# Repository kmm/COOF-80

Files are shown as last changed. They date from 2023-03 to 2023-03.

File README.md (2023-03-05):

# C00F-80

---
> A Lockdown-inspired Junkbox Z80 System

## Overview
Designed and built from on-hand parts in early 2020, COOF-80 (stylized in hexadecimal compatible as C00F-80) is Z80 system implementation that would be relatively sophisticated if it was 1980. Unfortunately it is not 1980, so it's more of an example of the most basic level of computing and a fun toy model computer to play with. Includes a simple and probably buggy interactive ROM monitor.

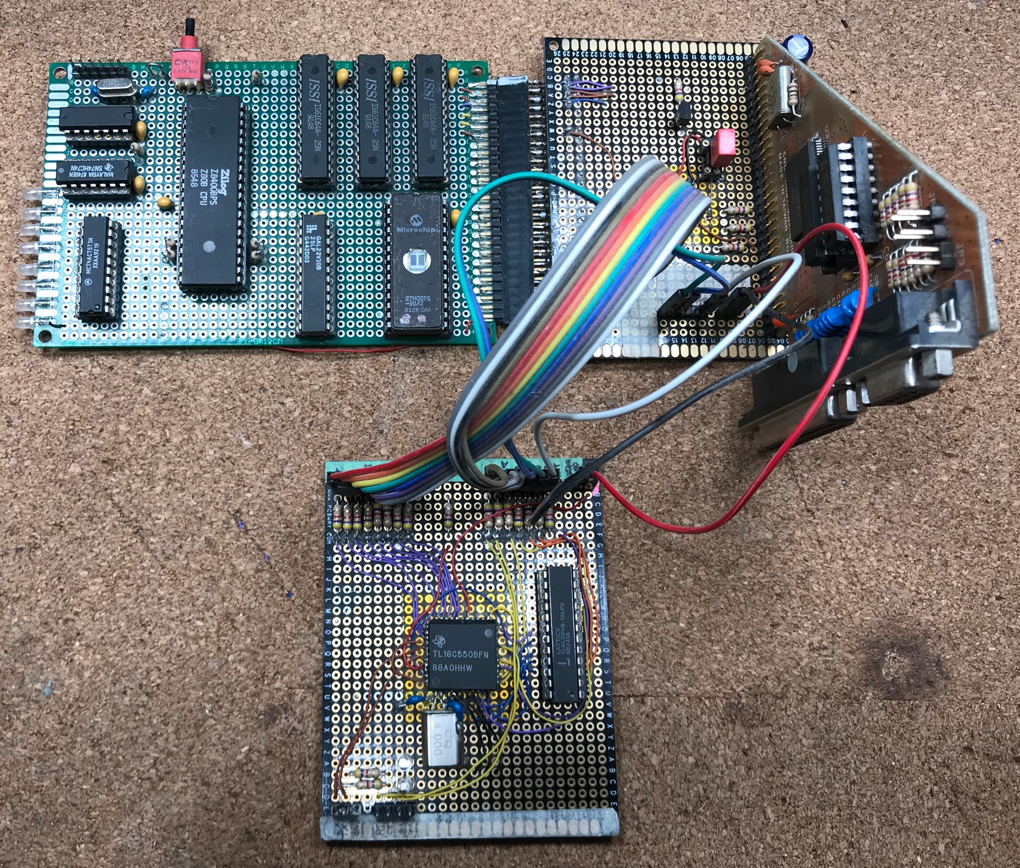
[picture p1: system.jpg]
A complete C00F-80 System


## Specifications
* Built using advanced perfboard technology
* Z80 microprocessor running at up to 4MHz
* Precision crystal oscillator with selectable clock divide factors (÷1, ÷2, ÷4)
* 8KB EPROM
* 24KB fast static RAM
* High-speed 16C550 UART for serial communication
* Byte-wide bank of blinkenlights for efficient human interfacing

## Included Files
* **/Design**
    * **C80-schematic.pdf**
    * **C80-schematic.png**
        * Schematic in PDF and PNG format
    * **COOF-80/**
        * KICAD 6 project
        * Currently there is no PCB design
* **/ASM**
    * **MAKE.BAT**
        * Builds included files using TASM32 (not included, place in path)
        * Generated binary images in intel hex format are placed in ./bin/
    * **blinkenlights.asm**
        * Basically hello world
        * Implements ping-pong scrolling LED effect suitable for installation on the grille of a 1982 Pontiac Trans-Am
    * **z80monitor.asm**
        * ROM monitor for interactive development and debugging
        * Uses UART interface for console
* **/GAL**
    * **z80logic.PLD**
    * **z80logic.jed**
        * PLD equations and synthesized JEDEC file for system glue logic GAL
    * **16C550.PLD**
    * **16C550.jed**
        * PLD equations and synthesized JEDEC file for UART glue logic GAL
    * **z80logic.ods**
        * Prettified truth table of system glue logic in LibreOffice Calc format

## Development
* Firmware was built using TASM32 ('Telemark Assembler', not to be confused with 'Turbo Assembler'), a vintage freeware assembler for Windows (and apparently Linux). Source may or may not be directly compatible with other assemblers.
    * https://www.ticalc.org/archives/files/fileinfo/250/25051.html
* PLD code was built using ~~Atmel's~~ Microchip's WinCUPL
    * https://www.microchip.com/en-us/development-tool/WinCUPL
* ASM80 is quite handy for development
    * https://www.asm80.com/
* As is ZEMU by Joe Moore
    * http://www.z80.info/zip/zemu.zip
    * http://www.z80.info/z80emu.htm
## ROM Monitor
### CLI Commands
```
d[ump] <hexaddr> <hexlen>
	Dump <hexlen> bytes memory starting at <hexaddr>
x[ecute] <hexaddr>
	Jump to <hexaddr> and execute
c[all] <hexaddr>
	Call <hexaddr> and return to monitor
f[ill] <hexaddr> <hexlen> <hexval>
	Fill <hexlen> bytes starting at <hexaddr> with <hexval>
:ihxstring
	Load Intel hex string into memory
w[rite] <hexval> <hexaddr>
    Write <hexval> to memory location <hexaddr>
i[nput] <hexport>
	Read <hexport> and print the value (high order byte ignored)
o[utput] <hexport> <hexval>
	Write <hexval> to <hexport> (high order byte ignored)
```
### Monitor API Routines
```
Call IDs:
 	0x00 - NOP
 	0x01 - Get character from UART, returned in A
	0x02 - Send character in A to UART
	0x03 - Send zero-terminated string pointed to by HL to UART
	0x04 - Split rxbuf and place in argbuf
	0x05 - Convert byte in A to ASCII hex, leave two chars in HL
	0x06 - Convert two ASCII chars in HL to byte, leave byte in A
	0x07 - Delay number of loops specified by HL
	0x08 - Get argbuf address and return it in HL
	0x09 - Get rxbuf address and return it in HL
	0x0A - Get substring index in A from argbuf, return address in IX
Calling convention:
 	- Push call number on stack
	- Load registers as appropriate for the API call being used
	- Execute RST 08h
```

## Other Stuff
* ISA Bus
	* I've attempted to interface an ISA MDA card with some degree of success. I can configure the CRTC and get it into a mode that can be fed into a VGA monitor, but memory writes to the framebuffer are unreliable and I'm not sure why. May revisit this eventually when I get a 16 bit Salae Logic and can better watch the bus. Source for configuring the CRTC is included in ASM/extra/mda.asm, and is intended to be pasted into the monitor using the Intel hex handler. Hardware for doing this is undocumented at the moment, but the short of it is most of the signals just need to be connected since ISA is basically an 8088 bus and the Z80 is fairly close to begin with being a conceptual relative of the 8080.

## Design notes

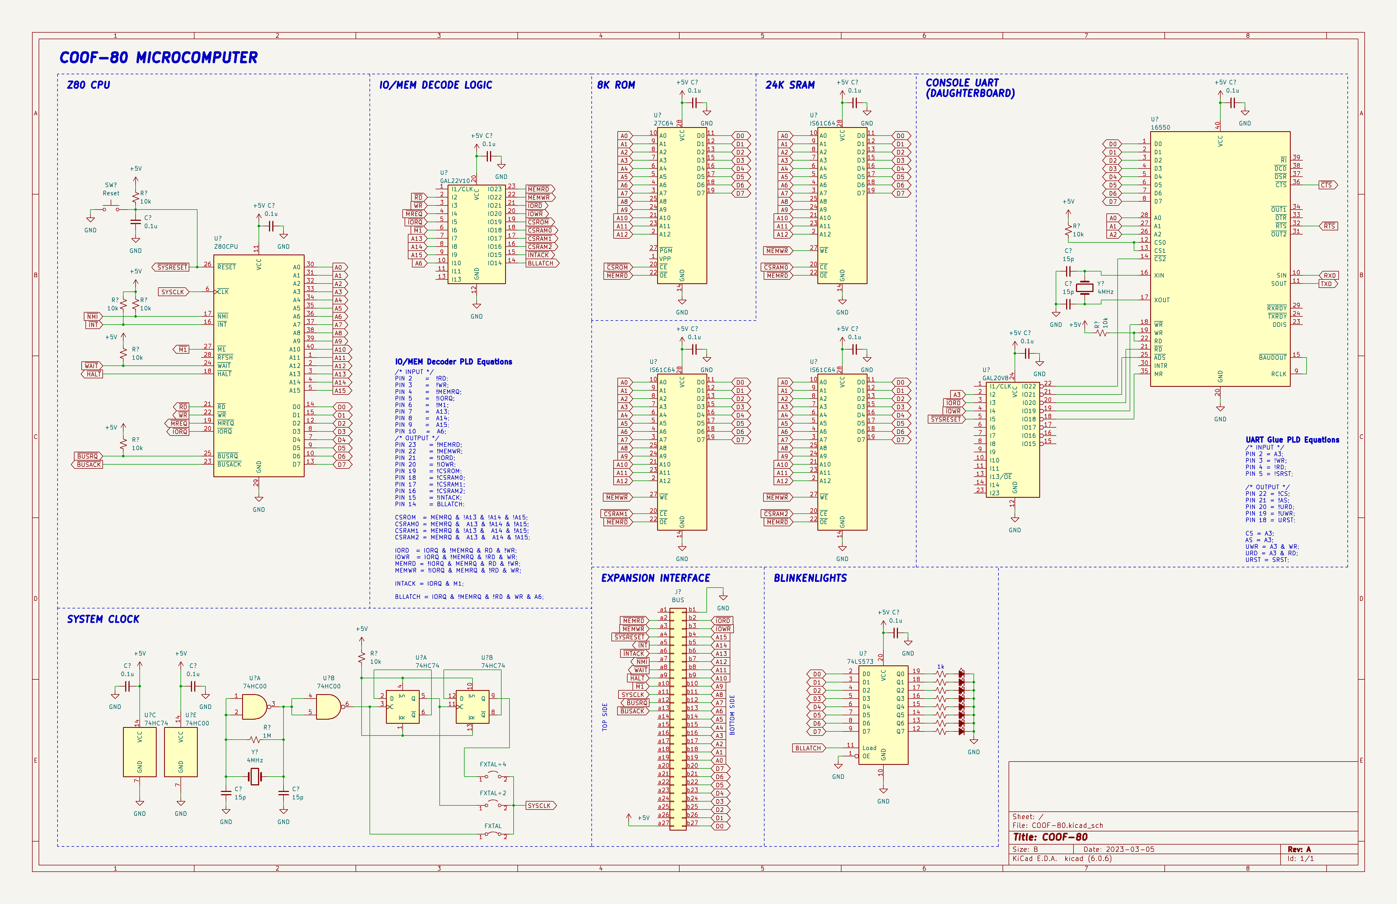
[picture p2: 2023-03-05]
Design/C80-schematic.png

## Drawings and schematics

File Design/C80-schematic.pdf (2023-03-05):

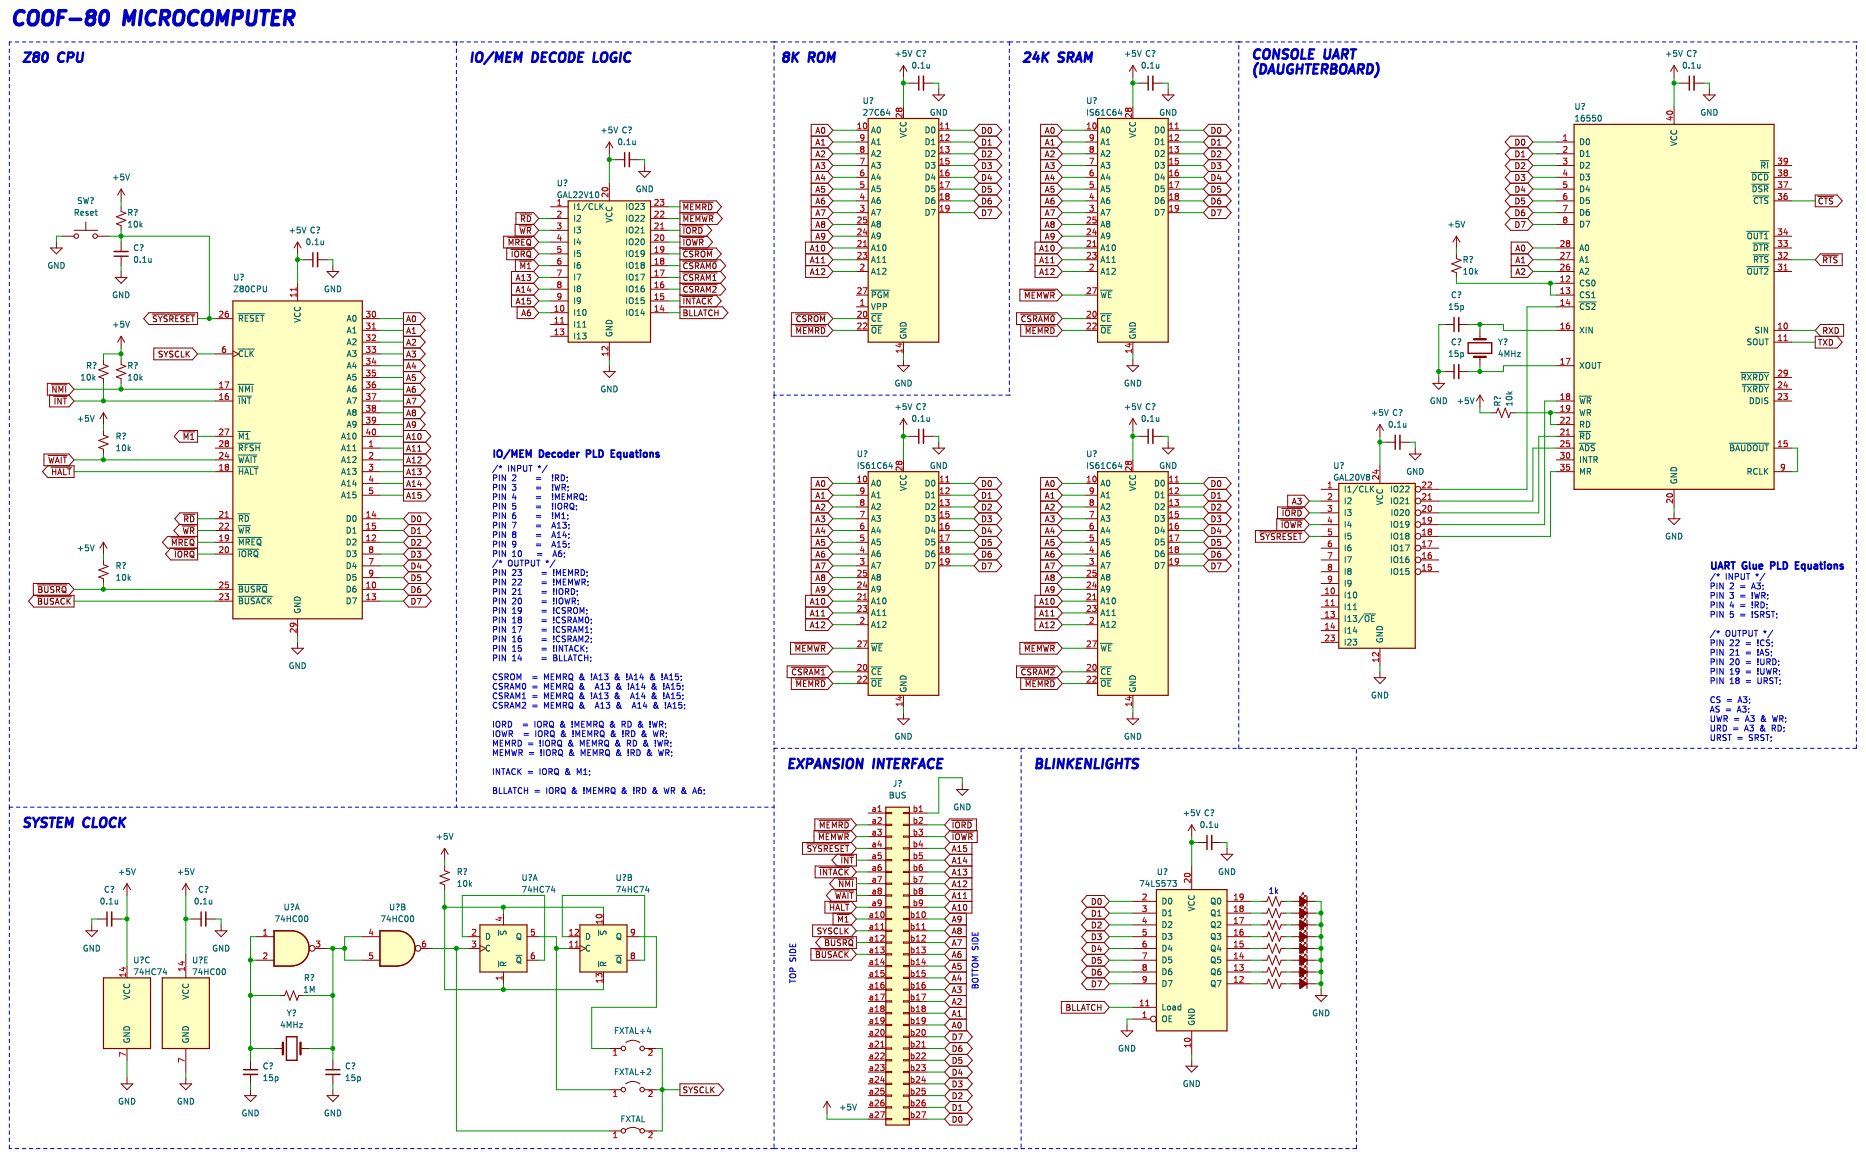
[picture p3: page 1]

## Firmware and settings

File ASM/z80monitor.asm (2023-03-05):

; COOFMON-Z80
; -----------------------------------------------------------------------------
; A simple ROM monitor for a simple Z80 computer, written during the first 
; weeks of lockdown for the unknown pathogen of unspecified origin in 1Q2020.
; (c) kmm 2020, MIT license
; -----------------------------------------------------------------------------
; CLI Commands
; d[ump] <hexaddr> <hexlen>
;	Dump <hexlen> bytes memory starting at <hexaddr>
; x[ecute] <hexaddr>
;	Jump to <hexaddr> and execute
; c[all] <hexaddr>
;	Call <hexaddr> and return to monitor
; f[ill] <hexaddr> <hexlen> <hexval>
;	Fill <hexlen> bytes starting at <hexaddr> with <hexval>
; :ihxstring
;	Load Intel hex string into memory
; w[rite] <hexval> <hexaddr>
;	Write <hexval> to memory location <hexaddr>
; i[nput] <hexport>
;	Read <hexport> and print the value (high order byte ignored)
; o[utput] <hexport> <hexval>
;	Write <hexval> to <hexport> (high order byte ignored)
; -----------------------------------------------------------------------------
; Also provides some "BIOS" type interrupt utility routines that can be 
; used by other code. Refer to implementations for more details.
; API call IDs:
; 	0x00 - NOP
; 	0x01 - Get character from UART, returned in A
;	0x02 - Send character in A to UART
;	0x03 - Send zero-terminated string pointed to by HL to UART
;	0x04 - Split rxbuf and place in argbuf
;	0x05 - Convert byte in A to ASCII hex, leave two chars in HL
;	0x06 - Convert two ASCII chars in HL to byte, leave byte in A
;	0x07 - Delay number of loops specified by HL
;	0x08 - Get argbuf address and return it in HL
;	0x09 - Get rxbuf address and return it in HL
;	0x0A - Get substring index in A from argbuf, return address in IX
; Calling convention:
; 	- Push call number on stack
;	- Load registers as appropriate for the API call being used
;	- Execute RST 08h

; UART Parameters
BAUDRATE			.equ 9600					; console baud rate
UARTCLK				.equ 4000000				; 16C550 crystal frequency 4 MHz
; Program Constants
STACKTOP			.equ 2040h 					; set stack pointer to 64 bytes above rom end
RXBUFLEN			.equ 160
TXBUFLEN			.equ 32
ARGBUFLEN			.equ 160
; Argument indexes, mostly for clarity in code
IDX_CMD				.equ 0
IDX_ARG_1			.equ 1
IDX_ARG_2			.equ 2
IDX_ARG_3			.equ 3
IDX_ARG_4			.equ 4
; UART ports and registers
#ifdef ZEMU
UART_BASE			.equ 20h					; Simulated UART starts at IO address 0x20 in ZEMU
UART_LSR			.equ UART_BASE+1
#else
UART_BASE			.equ 08h					; 16C550 starts at 0x08 in real hardware
UART_LSR			.equ UART_BASE+5
#endif
UART_RHR			.equ UART_BASE				; rx holding register
UART_THR			.equ UART_BASE				; tx holding register
UART_IER			.equ UART_BASE + 1			; interrupt enable register
UART_FCR			.equ UART_BASE + 2			; fifo control register
UART_ISR			.equ UART_BASE + 2			; interrupt status register
UART_LCR			.equ UART_BASE + 3			; line control register
UART_MCR			.equ UART_BASE + 4			; modem control register
UART_MSR			.equ UART_BASE + 6			; modem status register
UART_SPR			.equ UART_BASE + 7			; scratchpad register
UART_BDL			.equ UART_BASE				; baud rate divisor low byte at base + 0 (with lcr bit 7 set)
UART_BDH			.equ UART_BASE + 1			; baud rate divisor low byte at base + 1 (with lcr bit 7 set)

UART_LCR_bit_dle	.equ 80h					; lcr bit 7, divisor latch enable
UART_LCR_bit_brk	.equ 40h					; lcr bit 6, set break mode
UART_LCR_bit_sp		.equ 20h					; lcr bit 5, set parity
UART_LCR_bit_ep		.equ 10h					; lcr bit 4, even parity
UART_LCR_bit_pe		.equ 8h						; lcr bit 3, parity enable 
UART_LCR_bit_sb		.equ 4h						; lcr bit 2, stop bit length (0: 1, 1: 2)
UART_LCR_5b			.equ 0h						; lcr bits 0 and 1, 5 bits
UART_LCR_6b			.equ 1h						; lcr bits 0 and 1, 6 bits
UART_LCR_7b			.equ 2h						; lcr bits 0 and 1, 7 bits
UART_LCR_8b			.equ 3h						; lcr bits 0 and 1, 8 bits

UART_LSR_bit_txe	.equ 6						; lsr bit 6, tx holding register and shift register empty
UART_LSR_bit_thre	.equ 5						; lsr bit 5, tx holding register empty
UART_LSR_bit_rxr	.equ 0						; lsr bit 0, rx data ready

uart_con_baudl		.equ UARTCLK/(16*BAUDRATE)	; baud rate divisor [uart clock / (16 * baud rate)]
uart_con_baudh		.equ 00h					; high byte not used

uart_con_lcr		.equ UART_LCR_8b			; 8, n, 1

; Static allocations
v_rxbuf				.equ STACKTOP+1	     		; 160 byte rx buffer
v_rxbufpos			.equ v_rxbuf+RXBUFLEN+1		; 1 byte rx buffer pointer
v_txbuf				.equ v_rxbufpos+1   		; 32 byte tx buffer
v_txbufpos			.equ v_txbuf+TXBUFLEN+1		; 1 byte tx buffer pointer
v_argbufpos   		.equ v_txbufpos+1			; the current position in the buffer
v_argcount    		.equ v_argbufpos+1			; the number of arguments found
v_argbuf      		.equ v_argcount+1			; the buffer that will hold the arguments
v_dump_start		.equ v_argbuf+1				; dump start variable (16 bit)
v_dump_length		.equ v_dump_start+2			; dump length variable (16 bit)
v_scratch			.equ v_dump_length+2		; scratch buffer

; Startup vector
start:	.org 0000h
	jp init
; Interrupt vectors
int8:	.org 0008h								; vector for INT 8 API calls
	jp int8_handler
; Main code start
init: .org 007Fh
	ld sp, STACKTOP								; set stack pointer
	call uart_init								; init uart
	ld hl, ansi_csi_clear
	call uart_putstr
	ld hl, ansi_csi_home
	call uart_putstr
	ld hl, ansi_bg_blue
	call uart_putstr
	ld hl, ansi_fg_yellow
	call uart_putstr
	ld hl, hello								; load address of string into hl (arg for uart_txstr)
    call uart_putstr							; send it
	ld hl, ansi_bg_black
	call uart_putstr
	ld hl, ansi_fg_white
	call uart_putstr	
	ld hl, crlf									; send a CRLF
	call uart_putstr
	ld hl, prompt								; send a prompt
	call uart_putstr
	ld a, 0
	ld (v_rxbufpos), a							; initialize the RX buffer position
	jp mainloop
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

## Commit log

2023-03-05 Minor informational changes to monitor
    [COOF-80.kicad_pcb, COOF-80.kicad_sch]
2023-03-05 Fixes to schematic
    + Added taps/jumpers to system clock divider
    + Fixed UART wiring
    [COOF-80.kicad_sch]
